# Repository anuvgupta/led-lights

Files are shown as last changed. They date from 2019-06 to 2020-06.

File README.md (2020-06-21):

# led-lights

IoT audio-reactive LED strip lighting controller driven by Node.js, Arduino, NodeMCU/ESP8266 WebSockets, &amp; MSGEQ7 beat detection, with custom hardware and web &amp; iOS control panels.

## overview

iOS control panel app (or online webpage) uses WebSocket client APIs to send custom color presets & patterns as well as audio react settings to node.js WebSocket server.
ESP8266 connects to node.js server as a WebSocket client (from behind firewall). Server forwards presets, patterns & settings sent by iOS/web clients to ESP8266.
ESP8266 forwards this data to Arduino over hardware serial. Arduino receives data over SoftwareSerial, and then parses. Arduino drives RGB LED strip according to settings, using PWM, transistors, and external power.
MSGEQ7 takes an audio jack input from any source and filters frequencies into bass, treble, & 5 other bands. If audio reactive mode enabled, Arduino will read & transform MSGEQ7 output according to settings, and drive LEDs based on amplitude.

## schematic

Fritzing Schematic

## audio react

Audio reactive mode – recommended settings:

**Global**

-   Smoothing: `85-95`
-   Noise Gate: `30-40`

**Bass**

-   Channel: `1`
-   Invert: `off`
-   Pre-Amp: `70-120`
-   Post-Amp: `1`

**Treble**

-   Channel: `7`
-   Invert: `off`
-   Pre-Amp: `70-120`
-   Post-Amp: `1`

**Inverted Bass**

-   Channel: `1`
-   Invert: `on`
-   Pre-Amp: `60-90`
-   Post-Amp: `5-7`

## components

#### ESP8266

-   Model: [DIYmall ESP8266 ESP-01S](https://www.amazon.com/gp/product/B00O34AGSU/) with 1MB flash
-   Built with Arduino IDE instead of standard AT firmware
-   Uses standard ESP8266WiFi libraries and [arduinoWebSockets by Links2004](https://github.com/Links2004/arduinoWebSockets) client
-   Uses external 3V breadboard power source
-   NodeMCU is also compatible

#### Arduino

-   Model: [Elegoo Uno R3](https://www.amazon.com/Elegoo-EL-CB-001-ATmega328P-ATMEGA16U2-Arduino/dp/B01EWOE0UU) ([kit](https://www.elegoo.com/product/elegoo-uno-project-super-starter-kit/))
-   Uses SoftwareSerial (modified slightly to hold longer messages) on pins 6-7 to read patterns from ESP8266
-   Uses PWM on digital pins 9-11 to write color values to LED strip
    -   Pins connected to LED strip through N-channel MOSFET [TO-220](https://www.amazon.com/gp/product/B07CTJFG7M) transistors
    -   LED strip connected to external +12V power source
-   Arduino Nano is also compatible

#### WebSocket/HTTP Server

-   Runs on [anuv.me:3002/3003](http://anuv.me) (behind [leds.anuv.me](http://leds.anuv.me))
-   Built with node.js (express & WebSocket)

#### Control Panel

-   Hosted at [leds.anuv.me](http://leds.anuv.me)
-   Built with [block.js](https://github.com/anuvgupta/block.js), jQuery, WebSocket

&nbsp;  
*2019*

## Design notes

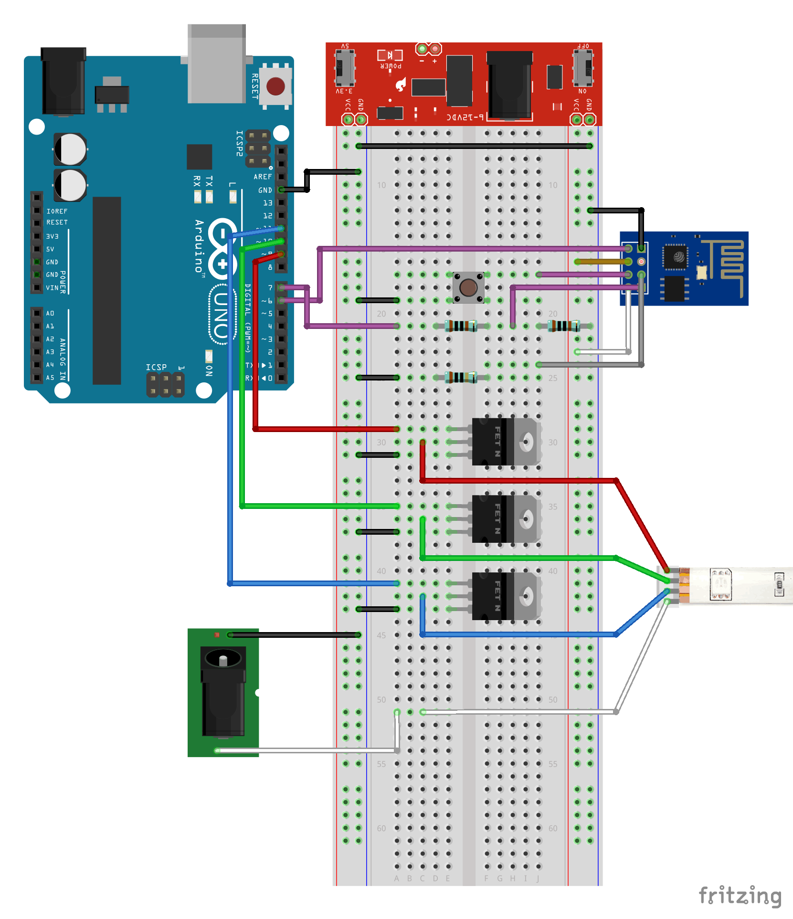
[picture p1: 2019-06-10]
circuit_schematics/esp_led_lights_bb.png

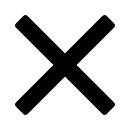
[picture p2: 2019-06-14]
nodejs_server/html/img/x_b.png

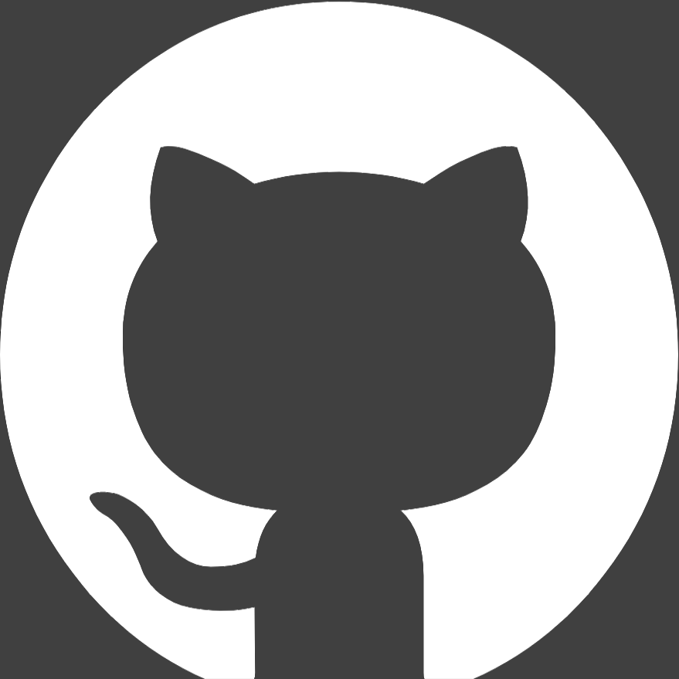
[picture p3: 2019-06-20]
nodejs_server/html/img/github_w.png

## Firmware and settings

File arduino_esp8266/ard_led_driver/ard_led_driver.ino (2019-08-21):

// includes
#include "SoftwareSerialMod.h"

// debug
#define DEBUG true

// LED PWM pins
#define REDPIN_L 9
#define GREENPIN_L 10
#define BLUEPIN_L 11
#define REDPIN_R 3
#define GREENPIN_R 5
#define BLUEPIN_R 6
// msgeq7 pins
#define STROBEPIN 2
#define RESETPIN 4
#define OUTRPIN A6
#define OUTLPIN A5

// msgeq7 settings
double l_preamp = 1.1; // double 0 - 2, (2 for low volume)
int l_postamp = 1; // int 1 - 20, (10 if inverted)
bool l_invert = false; // boolean
double r_preamp = 1.1;
int r_postamp = 1;
bool r_invert = false;
int noise = 20; // int 0 - 50
int smoothing = 95; // int 0 - 99
int l_channel = 0; // int 0 - 7
int r_channel = 1; // int 0 - 7
// esp8266 data
bool ready = false;
SoftwareSerial ESP8266(7, 8); // ARD 7 => ESP TX, ARD 8 => ESP RX
unsigned long lastTimestamp = 0;
// parsing data
int mb_i = 0;
char msgbuff[225]; // sufficient capacity (10 color limit for patterns)
char tokenbuff[20]; // 5(f) + 3(r) + 3(g) + 3(b) + 5(t) + 1(\0)
char databuff[6]; // 5(int dig max) + 1(\0)
// msgeq7 data
int bands[7];
int bands_record_l[7];
int bands_record_r[7];
// rgb data
double r_l = 0; // hue red (left)
double g_l = 0; // hue green (left)
double b_l = 0; // hue blue (left)
double r_r = 0; // hue red (right)
double g_r = 0; // hue green (right)
double b_r = 0; // hue blue (right)
double t = 0; // hue time
double n_r = 0; // new hue red
double n_g = 0; // new hue green
double n_b = 0; // new hue blue
double r_st = 0; // hue red fade
double g_st = 0; // hue green fade
double b_st = 0; // hue blue fade
double brightness = 100; // brightness
double speedmult = 100; // speed mult
int fade = 0; // transition (ms)
#define PRECISION 5 // 5 millisecond precision for fades
#define RESET_INTERVAL 15 // check ESP8266 every 5 minutes

void setup() {
  // init hardware and software serials
  Serial.begin(9600);
  ESP8266.begin(9600);

  if (DEBUG) Serial.println(F("LED Strip Driver"));

  // init LED PWM pins
  pinMode(REDPIN_L, OUTPUT);
  pinMode(GREENPIN_L, OUTPUT);
  pinMode(BLUEPIN_L, OUTPUT);
  red_l(0); green_l(0); blue_l(0);
  pinMode(REDPIN_R, OUTPUT);
  pinMode(GREENPIN_R, OUTPUT);
  pinMode(BLUEPIN_R, OUTPUT);
  red_r(0); green_r(0); blue_r(0);

  // init msgeq7 pins
  pinMode(STROBEPIN, OUTPUT);
  pinMode(RESETPIN, OUTPUT);
  pinMode(OUTRPIN, INPUT);
  pinMode(OUTLPIN, INPUT);
  digitalWrite(RESETPIN, LOW);
  digitalWrite(STROBEPIN, LOW);
  delay(1);
  // reset sequence
  digitalWrite(RESETPIN,  HIGH);
  delay(1);
  digitalWrite(RESETPIN,  LOW);
  digitalWrite(STROBEPIN, HIGH);
  delay(1);

  // init esp8266
  if (DEBUG) Serial.println(F("[nano] connecting to ESP8266"));
  ESP8266.println("reset");
  lastTimestamp = millis();
}

void loop() {
  // drive LED's
  red_l(r_l); green_l(g_l); blue_l(b_l);
  red_r(r_r); green_r(g_r); blue_r(b_r);

  // check time interval/reset esp8266
  
  if (resetRequired()) {
    unsigned long newTimestamp = millis();
    if (lastTimestamp > 0) {
      if (DEBUG) Serial.println("[nano] resetting ESP8266");
      ready = false;
      ESP8266.println("reset");
    }
    lastTimestamp = newTimestamp;
  }
  
  // read serial
  while (ESP8266.available() || Serial.available()) {
    if (mb_i >= 500) {
      msgbuff[499] = '\0';
      if (DEBUG) writeBuffer();
      mb_i = 0;
    } else {
      char c;
      if (ESP8266.available())
        c = ESP8266.read();
      else c = Serial.read();
      if (c != -1) {
        if (c == '\n') {
          msgbuff[mb_i] = '\0';
          if (DEBUG) writeBuffer();
          if (/*!ready &&*/ mb_i >= 5 && memcmp(msgbuff + mb_i - 5, "ready", 5) == 0) {
            if (DEBUG) Serial.println(F("[nano] connected to ESP8266"));
            ready = true;
          } else if (ready) {
            if (msgbuff[0] == 'h') {
              if (DEBUG) Serial.print(F("[update] new hue: "));
              if (DEBUG) Serial.println(msgbuff);
              double bright_prev = brightness;
              if (msgbuff[1] == 'm') brightness = 0;
              hue(DEBUG);
              if (msgbuff[1] == 'm') {
                brightness = bright_prev;
                music(DEBUG);
              }
            } else if (msgbuff[0] == 'p') {
              if (DEBUG) Serial.print(F("[update] new pattern: "));
              if (DEBUG) Serial.println(msgbuff);
              bool f = 1;
              while (uninterrupted()) {
                pattern(f && DEBUG);
                if (f) f = 0;
              }
            } else if (msgbuff[0] == 'b') {
              if (DEBUG) Serial.print(F("[update] new brightness: "));
              if (DEBUG) Serial.println(msgbuff);
              bright(DEBUG);
            } else if (msgbuff[0] == 's') {
              if (DEBUG) Serial.print(F("[update] new speed: "));
              if (DEBUG) Serial.println(msgbuff);
              speedm(DEBUG);
            } else if (msgbuff[0] == 'm') {
              if (DEBUG) Serial.println(F("[update] music mode"));
              music(DEBUG);
            } else if (msgbuff[0] == 'o') {
              smooth(DEBUG);
            } else if (msgbuff[0] == 'g') {
              noise_gate(DEBUG);
            } else if (msgbuff[0] == 'n') {
              if (DEBUG) Serial.println(F("[update] nil mode"));
            } else if (msgbuff[0] == 'l') {
              if (msgbuff[1] == 'p') {
                if (msgbuff[2] == 'r')
                  left_preamp(DEBUG);
                else if (msgbuff[2] == 'o')
                  left_postamp(DEBUG);
              } else if (msgbuff[1] == 'c')
                left_channel(DEBUG);
              else if (msgbuff[1] == 'i')
                left_invert(DEBUG);
            } else if (msgbuff[0] == 'r') {
              if (msgbuff[1] == 'p') {
                if (msgbuff[2] == 'r')
                  right_preamp(DEBUG);
                else if (msgbuff[2] == 'o')
                  right_postamp(DEBUG);
              } else if (msgbuff[1] == 'c')
                right_channel(DEBUG);
              else if (msgbuff[1] == 'i')
                right_invert(DEBUG);
            }
          }
          mb_i = 0;
        } else if (c != 0 && c >= 32 && c <= 126) {
          msgbuff[mb_i] = c;
          // Serial.println("[esp] msgbuff[" + String(mb_i) + "] " + String(msgbuff[mb_i]) + " (" + String((uint8_t) msgbuff[mb_i]) + ")");
          mb_i++;
        }
      }
    }
  }
}

// check if reset required
bool resetRequired() {
  // check time interval
  unsigned long newTimestamp = millis();
  unsigned long interval = 60000;
  interval *= RESET_INTERVAL;
  return ready && newTimestamp - lastTimestamp >= interval;
}

// check if current process should be interrupted
bool uninterrupted() {
  return ready && ESP8266.available() <= 0 && Serial.available() <= 0 && !resetRequired();
}

// process brightness from msgbuff
void bright(bool v) {
  int i, j;
  for (i = 1, j = 0; j < 3; i++, j++)
    databuff[j] = msgbuff[i];
  databuff[3] = '\0';
  brightness = atoi(databuff);
  if (v) { Serial.print("[nano] brightness – "); Serial.println(brightness); }
  red_l(r_l); green_l(g_l); blue_l(b_l);
  red_r(r_r); green_r(g_r); blue_r(b_r);
}

// process speed from msgbuff
void speedm(bool v) {
  int i, j;
  for (i = 1, j = 0; j < 3; i++, j++)
    databuff[j] = msgbuff[i];
  databuff[3] = '\0';
  speedmult = atoi(databuff);
  if (v) { Serial.print("[nano] speed – "); Serial.println(speedmult); }
  red_l(r_l); green_l(g_l); blue_l(b_l);
  red_r(r_r); green_r(g_r); blue_r(b_r);
}

// process hue from msgbuff
void hue(bool v) {
  // parse message data
  int i, j;
  // parse left
  for (i = 1 + 2, j = 0; j < 3; i++, j++)
    databuff[j] = msgbuff[i];
  databuff[3] = '\0';
  n_r = atoi(databuff);
  for (i = 1 + 5, j = 0; j < 3; i++, j++)
    databuff[j] = msgbuff[i];
  databuff[3] = '\0';
  n_g = atoi(databuff);
  for (i = 1 + 8, j = 0; j < 3; i++, j++)
    databuff[j] = msgbuff[i];
  databuff[3] = '\0';
  n_b = atoi(databuff);
  r_l = n_r; g_l = n_g; b_l = n_b;
  // parse right
  for (i = 1 + 2 + 10, j = 0; j < 3; i++, j++)
    databuff[j] = msgbuff[i];
  databuff[3] = '\0';
  n_r = atoi(databuff);
  for (i = 1 + 5 + 10, j = 0; j < 3; i++, j++)
    databuff[j] = msgbuff[i];
  databuff[3] = '\0';
  n_g = atoi(databuff);
  for (i = 1 + 8 + 10, j = 0; j < 3; i++, j++)
    databuff[j] = msgbuff[i];
  databuff[3] = '\0';
  n_b = atoi(databuff);
  r_r = n_r; g_r = n_g; b_r = n_b;
  if (v) {
    Serial.print(F("[nano] hue – LEFT  rgb(")); Serial.print(r_l); Serial.print(F(", ")); Serial.print(g_l); Serial.print(F(", ")); Serial.print(b_l); Serial.println(")");
    Serial.print(F("             RIGHT rgb(")); Serial.print(r_r); Serial.print(F(", ")); Serial.print(g_r); Serial.print(F(", ")); Serial.print(b_r); Serial.println(")");
  }
  // change color
  red_l(r_l); green_l(g_l); blue_l(b_l);
  red_r(r_r); green_r(g_r); blue_r(b_r);
}

// process pattern from msgbuff
void pattern(bool v) {
  // match left and right
  r_r = r_l; g_r = g_l; b_r = b_l;
  red_l(r_l); green_l(g_l); blue_l(b_l);
  red_r(r_r); green_r(g_r); blue_r(b_r);
  // loop through tokens
  for (int z = 1; uninterrupted() && tokenize(tokenbuff, msgbuff + 1, ',', z); z++) {
    fade = 0; // reset fade to default (none)
    // parse message data
    int i, j;
    for (i = 0, j = 0; j < 5; i++, j++)
      databuff[j] = tokenbuff[i];
    databuff[5] = '\0';
    fade = atoi(databuff);
    for (i = 5, j = 0; j < 3; i++, j++)
      databuff[j] = tokenbuff[i];
    databuff[3] = '\0';
    n_r = atoi(databuff);
    for (i = 8, j = 0; j < 3; i++, j++)
      databuff[j] = tokenbuff[i];
    databuff[3] = '\0';
    n_g = atoi(databuff);
    for (i = 11, j = 0; j < 3; i++, j++)
      databuff[j] = tokenbuff[i];
    databuff[3] = '\0';
    n_b = atoi(databuff);
    for (i = 14, j = 0; j < 5; i++, j++)
      databuff[j] = tokenbuff[i];
    databuff[5] = '\0';
    t = atoi(databuff);
    if (v) { Serial.print(F("[nano] fade – ")); Serial.print(fade); Serial.println(F("ms")); }
    if (v) { Serial.print(F("[nano] hue – rgb(")); Serial.print(n_r); Serial.print(F(", ")); Serial.print(n_g); Serial.print(F(", ")); Serial.print(n_b); Serial.print(")"); Serial.print(" – "); Serial.print(t); Serial.println("ms"); }
    // fade into color
    fadeColor();
    // hold color for time
    for (j = t / PRECISION / (speedmult / 100.0); uninterrupted() && j > 0; j--) {
      delay(PRECISION);
    }
  }
  if (v) Serial.println("[nano] repeat");
}

// fade into current color
void fadeColor() {
  // perform fade if exists
  if (fade != 0) {
    r_st = ((double) PRECISION) * (n_r - r_l) / ((double) fade);
    g_st = ((double) PRECISION) * (n_g - g_l) / ((double) fade);
    b_st = ((double) PRECISION) * (n_b - b_l) / ((double) fade);
    for (int z = fade / PRECISION / (speedmult / 100.0); uninterrupted() && z > 0; z--) {
      r_l += r_st; g_l += g_st; b_l += b_st;
      if (r_l < 0) r_l = 0; if (r_l > 255) r_l = 255;
      if (g_l < 0) g_l = 0; if (g_l > 255) g_l = 255;
      if (b_l < 0) b_l = 0; if (b_l > 255) b_l = 255;
      r_r = r_l; g_r = g_l; b_r = b_l;
      red_l(r_l); green_l(g_l); blue_l(b_l);
      red_r(r_r); green_r(g_r); blue_r(b_r);
      delay(PRECISION);
    }
  }
  // change final color
  r_l = n_r; g_l = n_g; b_l = n_b;
  r_r = r_l; g_r = g_l; b_r = b_l;
  red_l(r_l); green_l(g_l); blue_l(b_l);
  red_r(r_r); green_r(g_r); blue_r(b_r);
}

// music reactive mode
void music(bool v) {
  while (uninterrupted()) {
    // pulse strobe to cycle bands
    for (int i = 0; i < 7; i++) {
      // cycle
      digitalWrite(STROBEPIN, LOW);
      delayMicroseconds(100);
      // read
      bands[i] = analogRead(OUTRPIN) + analogRead(OUTLPIN);
      digitalWrite(STROBEPIN, HIGH);
      delayMicroseconds(1);
      double level;
      if (i == l_channel) {
        level = bands[i];
        // pre-amplify
        level *= l_preamp;
        // correct
        level /= 2.0;
        level *= 255.0 / 1023.0;
        // round
        level /= 5.0;
        level = (int) level;
        level *= 5.0;
        // post-amplify
        level *= l_postamp;
        // bound
        if (level <= noise) level = 0;
        if (level > 255) level = 255;
        // smooth
        if (smoothing > 0) {
          double weight = (smoothing / 100.0);
          level = (level * (1.0 - weight)) + (bands_record_l[i] * weight);
        }
        // save
        bands_record_l[i] = level;
        // invert
        if (l_invert) level = 255 - level;
        level /=  255.0;
        red_l(((double) r_l) * level);
        green_l(((double) g_l) * level);
        blue_l(((double) b_l) * level);
      }
      if (i == r_channel) {
        level = bands[i];
        level *= r_preamp;
        level /= 2.0;
        level *= 255.0 / 1023.0;
        level /= 5.0;
        level = (int) level;
        level *= 5.0;
        level *= r_postamp;
        if (level <= noise) level = 0;
        if (level > 255) level = 255;
        if (smoothing > 0) {
          double weight = (smoothing / 100.0);
          level = (level * (1.0 - weight)) + (bands_record_r[i] * weight);
        }
        bands_record_r[i] = level;
        if (r_invert) level = 255 - level;
        level /=  255.0;
        red_r(((double) r_r) * level);
        green_r(((double) g_r) * level);
        blue_r(((double) b_r) * level);
      }
    }
  }
  if (!uninterrupted()) {
    red_l(0); green_l(0); blue_l(0);
    red_r(0); green_r(0); blue_r(0);
  }
}

// set smoothing
void smooth(int v) {
  int i, j;
  for (i = 1, j = 0; j < 3; i++, j++)
    databuff[j] = msgbuff[i];
  databuff[3] = '\0';
  smoothing = atoi(databuff);
  if (v) { Serial.print("[nano] smoothing – "); Serial.println(smoothing); }
}

// set noise gate
void noise_gate(int v) {
  int i, j;
  for (i = 1, j = 0; j < 3; i++, j++)
    databuff[j] = msgbuff[i];
  databuff[3] = '\0';
  noise = atoi(databuff);
  if (v) { Serial.print("[nano] noise gate – "); Serial.println(noise); }
}

// set left channel
void left_channel(int v) {
  int i, j;
  for (i = 2, j = 0; j < 1; i++, j++)
    databuff[j] = msgbuff[i];
  databuff[1] = '\0';
  l_channel = atoi(databuff);
  if (v) { Serial.print("[nano] left channel – "); Serial.println(l_channel); }
}
// set right channel
void right_channel(int v) {
  int i, j;
  for (i = 2, j = 0; j < 1; i++, j++)
    databuff[j] = msgbuff[i];
  databuff[1] = '\0';
  r_channel = atoi(databuff);
  if (v) { Serial.print("[nano] right channel – "); Serial.println(r_channel); }
}

// set left invert
void left_invert(int v) {
  int i, j;
  for (i = 2, j = 0; j < 1; i++, j++)
    databuff[j] = msgbuff[i];
  databuff[1] = '\0';
  l_invert = atoi(databuff);
  if (v) { Serial.print("[nano] left invert – "); Serial.println(l_invert); }
}
// set right invert
void right_invert(int v) {
  int i, j;
  for (i = 2, j = 0; j < 1; i++, j++)
    databuff[j] = msgbuff[i];
  databuff[1] = '\0';
  r_invert = atoi(databuff);
  if (v) { Serial.print("[nano] right invert – "); Serial.println(r_invert); }
}

// set left preamp
void left_preamp(int v) {
  int i, j;
  for (i = 3, j = 0; j < 3; i++, j++)
    databuff[j] = msgbuff[i];
  databuff[3] = '\0';
  l_preamp = atoi(databuff);
  l_preamp /= 100.0;
  if (v) { Serial.print("[nano] left preamp – "); Serial.println(l_preamp); }
}
// set right preamp
void right_preamp(int v) {
  int i, j;
  for (i = 3, j = 0; j < 3; i++, j++)
    databuff[j] = msgbuff[i];
  databuff[3] = '\0';
  r_preamp = atoi(databuff);
  r_preamp /= 100;
  if (v) { Serial.print("[nano] right preamp – "); Serial.println(r_preamp); }
}

// set left postamp
void left_postamp(int v) {
  int i, j;
  for (i = 3, j = 0; j < 3; i++, j++)
    databuff[j] = msgbuff[i];
  databuff[3] = '\0';
  l_postamp = atoi(databuff);
  if (v) { Serial.print("[nano] left postamp – "); Serial.println(l_postamp); }
}
// set right postamp
void right_postamp(int v) {
  int i, j;
  for (i = 3, j = 0; j < 3; i++, j++)
    databuff[j] = msgbuff[i];
  databuff[3] = '\0';
  r_postamp = atoi(databuff);
  if (v) { Serial.print("[nano] right postamp – "); Serial.println(r_postamp); }
}

// LED PWM functions
void red_l(int v) {
  analogWrite(REDPIN_L, (int) (brightness / 100.0 * ((double) v)));
}
void green_l(int v) {
  analogWrite(GREENPIN_L, (int) (brightness / 100.0 * ((double) v)));
}
void blue_l(int v) {
  analogWrite(BLUEPIN_L, (int) (brightness / 100.0 * ((double) v)));
}
void red_r(int v) {
  analogWrite(REDPIN_R, (int) (brightness / 100.0 * ((double) v)));
}
void green_r(int v) {
  analogWrite(GREENPIN_R, (int) (brightness / 100.0 * ((double) v)));
}
void blue_r(int v) {
  analogWrite(BLUEPIN_R, (int) (brightness / 100.0 * ((double) v)));
}

// convenience custom tokenizer
int tokenize(char* dst, char* src, char delim, int occ) {
  int o, b, e;
  e = -1;
  for (o = 0; o < occ; o++) {
      if (e > 0 && src[e] == '\0' && o < occ) return 0;
    b = e + 1;
    for (e = b; src[e] != '\0' && src[e] != delim; e++);
  }
  if (b == e) return 0;
  strncpy(dst, src + b, e - b);
  dst[e - b] = '\0';
  return 1;
}

// write message buffer to output serial
void writeBuffer() {
  if (msgbuff[0] == '[') {
    Serial.print(F("[esp:"));
    Serial.println(msgbuff + 1);
  } else {
    Serial.print(F("[serial] "));
    Serial.println(msgbuff);
  }
}

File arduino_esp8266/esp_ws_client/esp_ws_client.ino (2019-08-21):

// includes
#include <Arduino.h>
#include <ESP8266WiFi.h>
#include <ESP8266WiFiMulti.h>
#include <WebSocketsClient.h>
#include <Hash.h>
#include "secrets.h"

// wifi bars
ESP8266WiFiMulti wifi;
WebSocketsClient ws;

// constants
#define SERIAL Serial
#define ESP_DEBUG_V false
#define DEBUG_MODE false
//#define SERVER "10.0.1.40"
//#define PORT 30003
#define SERVER "leds.anuv.me"
#define PORT 3003

// parsing data
int mb_i = 0;
char msgbuff[500];

void wsEventHandler(WStype_t type, uint8_t* payload, size_t length) {
  switch (type) {
    case WStype_DISCONNECTED:
      if (DEBUG_MODE) SERIAL.printf("[ws] disconnected\n");
      restartESP();
      break;
    case WStype_CONNECTED:
      if (DEBUG_MODE) SERIAL.printf("[ws] connected to %s\n", payload);
      if (DEBUG_MODE) SERIAL.printf("[ws] syncing as arduino\n");
      ws.sendTXT(DEVICE_SYNC_JSON);
      break;
    case WStype_TEXT:
      // SERIAL.printf("[ws] received text – %s\n", payload);
      if (length > 224) payload[224] = '\0';
      if (memcmp(payload, "@arduinosync", 12) == 0) {
        if (DEBUG_MODE) SERIAL.printf("[ws] synced as arduino\n");
        if (DEBUG_MODE) SERIAL.printf("[ws] authenticating\n");
        ws.sendTXT(SECRET_AUTH_JSON); // authenticate with password
      } else if (memcmp(payload, "@auth", 5) == 0) {
        if (DEBUG_MODE) SERIAL.printf("[ws] authenticated\n");
        Serial.printf("ready\n");
      } else if (memcmp(payload, "@p-", 3) == 0) {
        if (DEBUG_MODE) SERIAL.printf("[ws] new pattern - %s\n", payload + 3);
        Serial.printf("p%s\n", payload + 3);
      } else if (memcmp(payload, "@h-", 3) == 0) {
        if (DEBUG_MODE) SERIAL.printf("[ws] new hue - %s\n", payload + 3);
        Serial.printf("hh%s\n", payload + 3);
      } else if (memcmp(payload, "@hm", 3) == 0) {
        if (DEBUG_MODE) SERIAL.printf("[ws] new hue (music mode) - %s\n", payload + 3);
        Serial.printf("hm%s\n", payload + 3);
      } else if (memcmp(payload, "@b-", 3) == 0) {
        if (DEBUG_MODE) SERIAL.printf("[ws] new brightness - %s\n", payload + 3);
        Serial.printf("b%s\n", payload + 3);
      } else if (memcmp(payload, "@s-", 3) == 0) {
        if (DEBUG_MODE) SERIAL.printf("[ws] new speed mult - %s\n", payload + 3);
        Serial.printf("s%s\n", payload + 3);
      } else if (memcmp(payload, "@hb", 3) == 0) {
        if (DEBUG_MODE) SERIAL.printf("[ws] heartbeat\n");
        ws.sendTXT("{\"event\":\"arduino_heartbeat\"}");
      } else if (memcmp(payload, "@nil", 4) == 0) {
        if (DEBUG_MODE) SERIAL.printf("[ws] nil mode\n");
        Serial.printf("nil\n");
      } else if (memcmp(payload, "@music", 6) == 0) {
        if (DEBUG_MODE) SERIAL.printf("[ws] music mode\n");
        Serial.printf("music\n");
      } else if (memcmp(payload, "@sm", 3) == 0) {
        if (DEBUG_MODE) SERIAL.printf("[ws] new smoothing - %s\n", payload + 3);
        Serial.printf("o%s\n", payload + 3);
      } else if (memcmp(payload, "@ng", 3) == 0) {
        if (DEBUG_MODE) SERIAL.printf("[ws] new noise gate - %s\n", payload + 3);
        Serial.printf("g%s\n", payload + 3);
      } else if (memcmp(payload, "@lc", 3) == 0) {
        if (DEBUG_MODE) SERIAL.printf("[ws] new left channel - %s\n", payload + 3);
        Serial.printf("lc%s\n", payload + 3);
      } else if (memcmp(payload, "@rc", 3) == 0) {
        if (DEBUG_MODE) SERIAL.printf("[ws] new right channel - %s\n", payload + 3);
        Serial.printf("rc%s\n", payload + 3);
      } else if (memcmp(payload, "@lpr", 4) == 0) {
        if (DEBUG_MODE) SERIAL.printf("[ws] new left preamp - %s\n", payload + 3);
        Serial.printf("lpr%s\n", payload + 4);
      } else if (memcmp(payload, "@rpr", 4) == 0) {
        if (DEBUG_MODE) SERIAL.printf("[ws] new right preamp - %s\n", payload + 3);
        Serial.printf("rpr%s\n", payload + 4);
      } else if (memcmp(payload, "@lpo", 4) == 0) {
        if (DEBUG_MODE) SERIAL.printf("[ws] new left postamp - %s\n", payload + 3);
        Serial.printf("lpo%s\n", payload + 4);
      } else if (memcmp(payload, "@rpo", 4) == 0) {
        if (DEBUG_MODE) SERIAL.printf("[ws] new right postamp - %s\n", payload + 3);
        Serial.printf("rpo%s\n", payload + 4);
      } else if (memcmp(payload, "@li", 3) == 0) {
        if (DEBUG_MODE) SERIAL.printf("[ws] new left invert - %s\n", payload + 3);
        Serial.printf("li%s\n", payload + 3);
      } else if (memcmp(payload, "@ri", 3) == 0) {
        if (DEBUG_MODE) SERIAL.printf("[ws] new right invert - %s\n", payload + 3);
        Serial.printf("ri%s\n", payload + 3);
      }
      break;
    case WStype_BIN:
      if (DEBUG_MODE) SERIAL.printf("[ws] received binary data (length %u):\n", length);
      hexdump(payload, length);
      // ws.sendBIN(payload, length);
      break;
  }
}

void setup() {
  SERIAL.begin(9600);
  SERIAL.setDebugOutput(ESP_DEBUG_V);
  if (DEBUG_MODE) SERIAL.println("\n\n");
  if (DEBUG_MODE) SERIAL.println("ESP8266");
  for (uint8_t t = 2; t > 0; t--) {
    if (DEBUG_MODE) SERIAL.printf("[boot] wait %d\n", t);
    if (DEBUG_MODE) SERIAL.flush();
    delay(1000);
  }
  if (DEBUG_MODE) SERIAL.printf("[wifi] connecting to %s\n", &secret_ssid);
  wifi.addAP(SECRET_SSID, SECRET_PASS);
  while (wifi.run() != WL_CONNECTED) delay(50);
  if (DEBUG_MODE) SERIAL.printf("[wifi] connected\n");
  if (DEBUG_MODE) SERIAL.printf("[ws] connecting\n");
  ws.begin(SERVER, PORT, "/");
  ws.onEvent(wsEventHandler);
  // ws.setAuthorization("user", "Password");
  ws.setReconnectInterval(5000);
  
  // start heartbeat (optional)
  // ping server every 15000 ms
  // expect pong from server within 3000 ms
  // consider connection disconnected if pong is not received 2 times
   ws.enableHeartbeat(15000, 3000, 2);
}

void loop() {
  ws.loop();
  if (Serial.available()) {
    if (mb_i >= 500) {
      msgbuff[499] = '\n';
      if (DEBUG_MODE) Serial.println(msgbuff);
      mb_i = 0;
    } else {
      char c = Serial.read();
      if (c != -1) {
        // Serial.print(c);
        if (c == '\n') {
          msgbuff[mb_i] = '\0';
          if (memcmp(msgbuff + mb_i - 5, "reset", 5) == 0) {
            restartESP();
          }
          mb_i = 0;
        } else if (c != 0 && c > 32 && c < 126) {
          msgbuff[mb_i] = c;
          mb_i++;
        }
      }
    }
  }
}

void restartESP() {
  if (DEBUG_MODE) Serial.println(F("[boot] resetting...\n"));
  ESP.restart();
}

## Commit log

2019-06-10 arduino and esp8266 sketches
2019-07-07 status timer
2019-07-07 Revert "status timer"
    This reverts commit 2a3cd43af6f177e1ea4d298babb628471aa362e2.
2019-07-18 on, off, resume current
2019-07-30 major upgrade
    - refactoring & code style
    - web client modular image loading, select block
    - modularize websocket server
    - multiple devices, device list (todo ios client)
    - left & right led strip channels (todo ios client)
    - music reactive mode integrated (todo live settings)
    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
2019-08-19 music menu
    - add music reactive live settings menu (ios todo)
    - fix test script
    - arrow functions on server
    - web client title
    [ard_led_driver.ino, esp_ws_client.ino]
2019-08-20 fix: send music settings to arduino
2019-08-20 more fixes
    - major change: current music contains hue (ios todo)
    - web: play music on preset double click (ios todo)
    - web: refactor "music" to "audio" (ios todo)
    - node: trim data & abstract send_device_list
    - node: correct arduino invert settings
2019-08-20 fix: reduce device_list events
2019-08-21 Upgrade iOS client to match web
    Fully functional iOS client with:
    - audio react menu
    - multiple device targets
    - device selector menu
    - updated event names
2020-01-26 switch
    update copyright, remove commented http server code, add switch page
